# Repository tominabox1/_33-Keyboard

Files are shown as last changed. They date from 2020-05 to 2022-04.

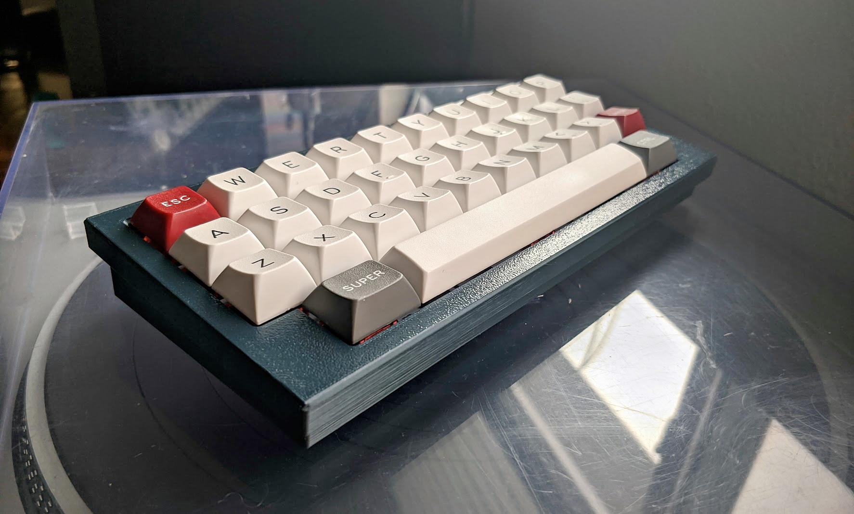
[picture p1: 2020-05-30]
Rev2/Cases/_33 Case Image.png

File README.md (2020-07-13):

# _33-Keyboard


This is the STL for the _33 keyboard designed by tominabox1 (discord @tominabox1#7884) Modded to be more printable by P3D.

Recommend printing with top against the bed. Be sure to use a small amount of supports for the PCB mounts

3 x M2 8mm machine screws are used for the bottom cover.

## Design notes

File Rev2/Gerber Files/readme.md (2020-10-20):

# _33 Rev2 Bill of Materials (BOM)

| *Qty 	| *Designator 	| Description / Value 	| *Package/Footprint  	|
|:-:	|:-:	|:-:	|:-:	|
| 4 	| C1, C3, C6, C7 	| .1u 	| 0603 	|
| 1 	| C4 	| 1u 	| 0603 	|
| 1 	| C8 	| 4.7u 	| 0603 	|
| 35 	| D1, D2, D3, D4, D5, D6, D7, D8, D9, D10, D11, D12, D13, D14, D15, D16, D17, D18, D19, D20, D21, D22, D23, D24, D25, D26, D27, D28, D29, D30, D31, D32, D33, D34, D35 	| 1N4148 	| SOD123 	|
| 2 	| D36, D37 	| 1N4148 	| SOD123 	|
| 1 	| F1 	| 500mA fuse 	| 0603 	|
| 2 	| R1, R2 	| 22 	| 0603 	|
| 2 	| R3, R6 	| 10k 	| 0603 	|
| 2 	| R4, R5 	| 5.1k 	| 0603 	|
| 1 	| SW1 	| TL3342 	| keebio:SW_SPST_3x3 	|
| 1 	| U2 	| ATmega32U2-AU 	| Package_QFP:TQFP-32_7x7mm_P0.8mm 	|
| 1 	| USB1 	| HRO-TYPE-C-31-M-12 	| Type-C:HRO-TYPE-C-31-M-12-HandSoldering 	|
| 1 	| Y1 	| CSTNE16M0V530000R0 	| Crystal:Resonator_SMD_muRata_CSTxExxV-3Pin_3.0x1.1mm 	|

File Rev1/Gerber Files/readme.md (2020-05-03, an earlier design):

# _33 Bill of Materials (BOM)

|Ref|Qnty|Value|Footprint|
|---|----|-----|---|
|C1, C3, C6, C7|4|.1u|0805|
|C2, C5|2|22p|0805|
|C4|1|1u|0805|
|C8|1|4.7u|0805|
|D1, D2, D3, D4, D5, D6, D7, D8, D9, D10, D11, D12, D13, D14, D15, D16, D17, D18, D19, D20, D21, D22, D23, D24, D25, D26, D27, D28, D29, D30, D31, D32, D33, D34, D35|35|1N4148|SOD-23|
|F1|1|Fuse|0603|
|R1, R2|2|22|0805|
|R3, R6|2|10k|0805|
|R4, R5|2|5.1k|0805|
|SW1|1|Reset Switch|TL3342|
|U1|1|ATmega32U4-AU|TQFP-44|
|Y1|1|16 Mhz Crystal|FA238|
|USB|1|USB-C|HRO-TYPE-C-31-M12|

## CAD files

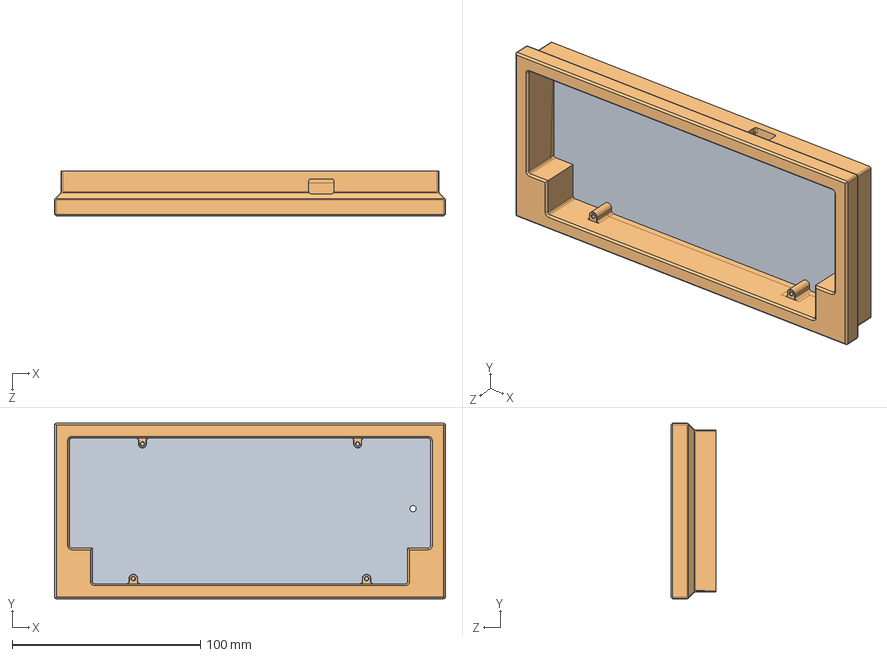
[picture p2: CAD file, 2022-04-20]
Rev2/Cases/_33_Case_Flat.STEP
207.6 x 93.2 x 24.1 mm

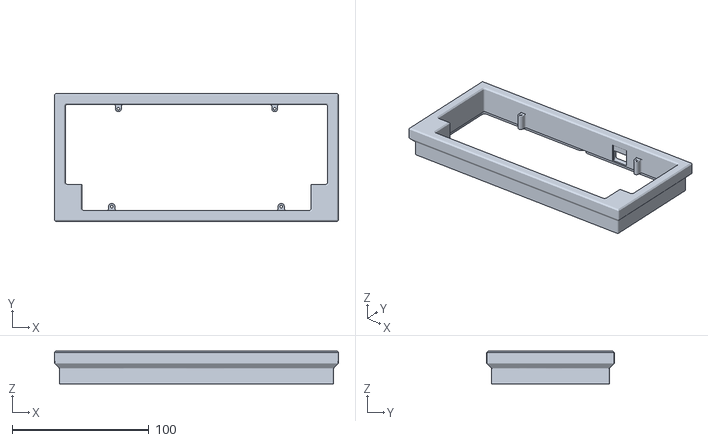
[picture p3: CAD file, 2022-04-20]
Rev2/Cases/_33_Case_Flat_Top.STL
207.5 x 93.2 x 24.1

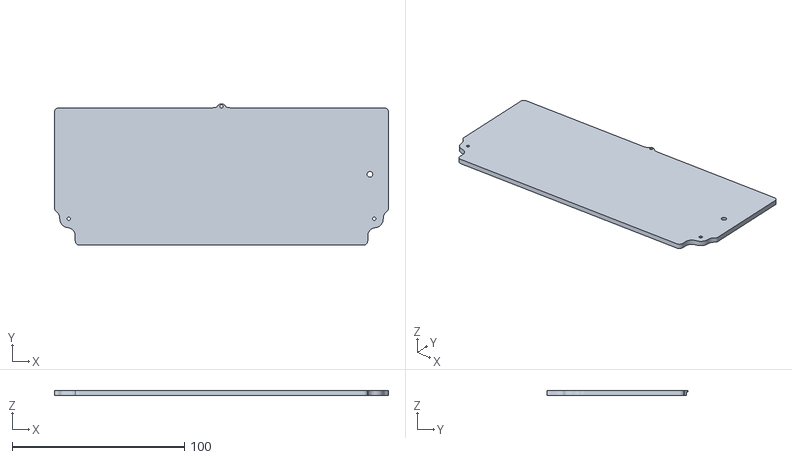
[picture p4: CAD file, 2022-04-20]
Rev2/Cases/_33_Case_Flat_Bottom.STL
194.0 x 82.0 x 3.00

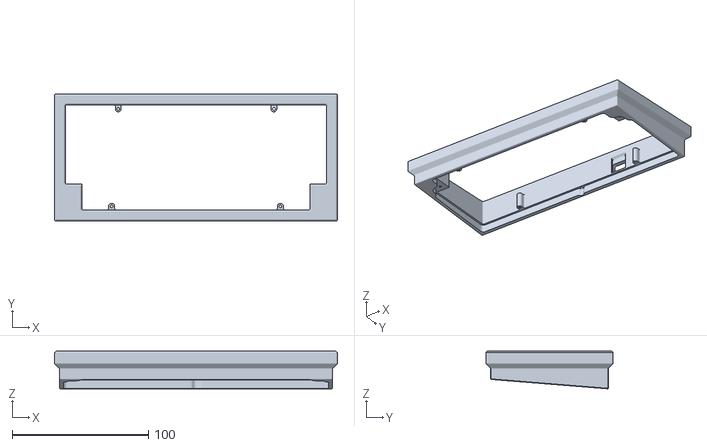
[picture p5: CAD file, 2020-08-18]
Rev2/Cases/_33 Top_P3D_Mod Rev 2.stl
207.6 x 93.2 x 27.6

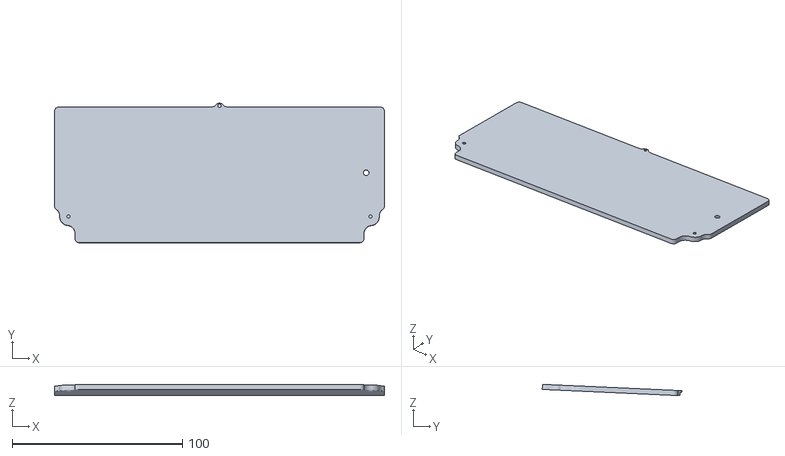
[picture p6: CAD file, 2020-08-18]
Rev2/Cases/_33 Bottom_P3D_Mod Rev 2.stl
194.0 x 82.1 x 6.67

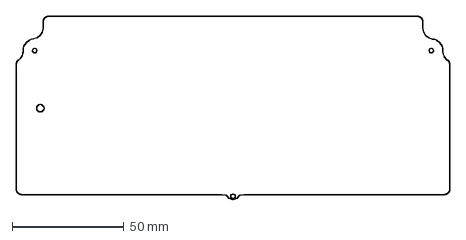
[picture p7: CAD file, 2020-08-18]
Rev2/Cases/_33 Bottom_P3D_Mod Rev 2 DXF.dxf
194.0 x 82.0 mm

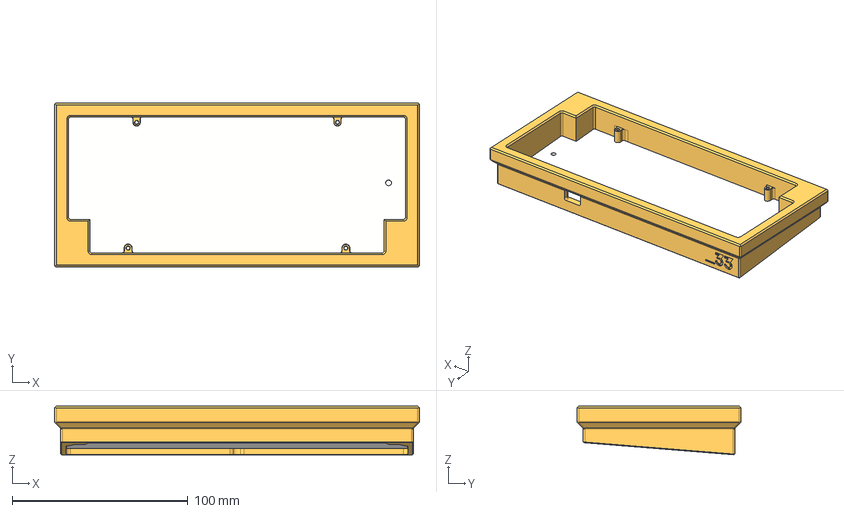
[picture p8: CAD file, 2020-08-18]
Rev2/Cases/_33_Case_P3D_MOD_Bottom_Revision_CAD v2.step
207.6 x 93.2 x 27.6 mm

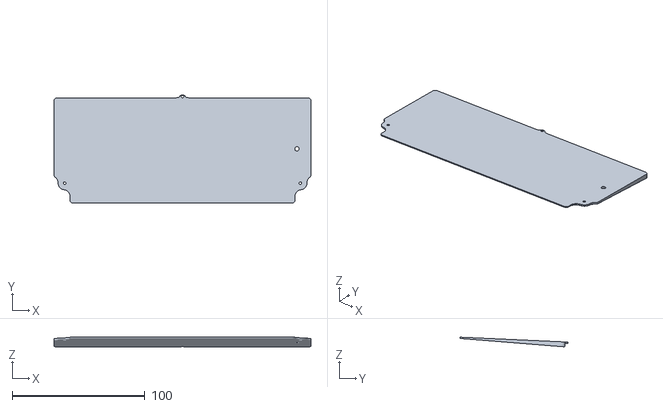
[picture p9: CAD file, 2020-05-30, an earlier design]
Rev1/Cases/_33 Bottom_P3D_Mod.stl
193.6 x 81.6 x 7.30

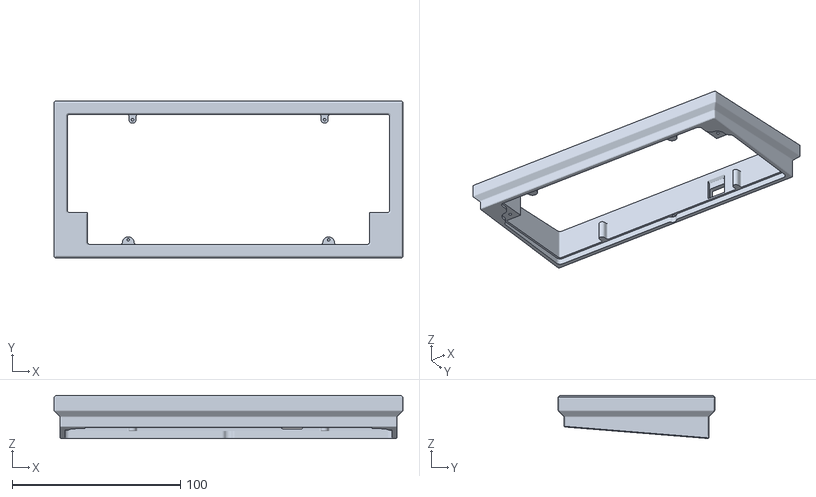
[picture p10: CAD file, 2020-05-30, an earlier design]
Rev1/Cases/_33 Top_P3D_Mod.stl
207.6 x 93.2 x 25.6

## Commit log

2020-03-24 Adding case.stl
    [Case.stl]
2020-03-26 Adding .step and big usb cutout version
    [Case_big_USB.stl, _33_Case_big_USB.step]
2020-04-21 Adding tydubs case designs
2020-05-03 Updated gerbers
    better reset switch type and moved jlc job number
2020-05-19 Added _33 R1 Case Mod
    [_33 Bottom_P3D_Mod.stl, _33 Top_P3D_Mod.stl, _33_Case_P3D_MOD v6.step]
2020-05-30 Added non meme bottom cover
    [_33 Bottom_P3D_Mod.stl, _33 Top_P3D_Mod.stl, _33_Case_P3D_MOD v6.step]
2020-05-30 Remove original case files
    [Case.stl, Case_big_USB.stl]
2020-07-13 Add P3D top compatible with r2 _33
    [_33 Top_P3D_Mod_rev2.stl]
2020-07-13 Remove obsolete .step
    [_33_Case_big_USB.step]
2020-07-13 Organized rev1
    [_33 Bottom_P3D_Mod.stl, _33 Top_P3D_Mod.stl]
2020-07-13 fix spacing of mount
    [_33 Top_P3D_Mod_rev2.stl]
2020-07-16 Add updated tydubs case
2020-08-18 Added P3D Case Mod Files
    [_33 Bottom_P3D_Mod Rev 2 DXF.dxf, _33 Bottom_P3D_Mod Rev 2.stl, _33 Bottom_P3D_Mod.stl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]
2020-10-20 Add rev2 source Gerbers
    [_33 Bottom_P3D_Mod Rev 2 DXF.dxf, _33 Bottom_P3D_Mod Rev 2.stl, _33 Bottom_P3D_Mod.stl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]
2022-01-07 fix trailing space
    [_33 Bottom_P3D_Mod Rev 2 DXF.dxf, _33 Bottom_P3D_Mod Rev 2.stl, _33 Top_P3D_Mod Rev 2.stl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]
2022-04-18 Flat bottom modification
    Modified "_33_Case_P3D_MOD_Bottom_Revision_CAD v2.step" file to create a zero-angle version
    [_33_Case_Flat.STEP, _33_Case_Flat_Bottom.STL, _33_Case_Flat_Top.STL]
